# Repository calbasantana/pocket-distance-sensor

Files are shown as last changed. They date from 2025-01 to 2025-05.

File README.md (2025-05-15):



# Introduction
When I had my old car, a 2018 Mazda CX-3, I was always getting frustrated with how hard it was to tell if I was close to another car or not when parking. My car didn't have a built-in proximity sensor, so I decided to take on this project to build one for it.

The idea being that if I had a distance sensor (light-based or sound-based) at the front of the car and hooked up the circuitry inside the car with the small screen, I could make it all work. However, I was in the middle of buying a new car and this project took on a different form, one of being a pocket distance sensor. It certainly isn't perfect, but it is a cool little thing. In the future, I would love to make it more compact.

# Materials
This pocket distance sensor makes use of the following:

- 3D-printed case
- Custom PCB
- Hardware parts

In the following sections, I will get into more details about each.

## 3D-Printed Case

I decided to go with something simple; something that could hold the battery and the screen with everything else in between.



There are a total of 4 files attached here for this case:

- Case Top
- Case Bottom
- Battery Cover
- 4X Magnet Cover

I personally did not end up using the Battery Cover I designed and I found the Magnet Covers to be unnecessary if you're using strong glue to keep the magnets in their place.

### Specifications & Material(s)
Below you can find the printer and material used.
#### 3D Printer
 Original Prusa Mini+
#### Material(s)
* [INLAND True Red PLA ($25.99)](https://www.amazon.com/Inland-PLA-Printer-Filament-1-75mm/dp/B09P22PTGG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
)

#### Software
 PrusaSlicer

##### Settings
  Layer Height: .2mm \
  Infill: 30% \
  Supports: Everywhere \
  Estimated Printing Time: 8 hours and 1 minutes

## Custom PCB

I decided to create a custom PCB for the pico, screen connections, and other hardware pieces to be more compact. I did this using EasyEDA (https://easyeda.com/).

Below you can see the schematics on EasyEDA:



And here you can see the PCB layout:



For convenience, I've attached the Gerber .zip file, which can be uploaded at this website for purchase: https://jlcpcb.com/?href=easyeda-home

Overall, it is very cheap to make a PCB, so I find myself doing large batches - the biggest pain is the shipping.

Once you do have your PCB, make sure to solder it appropriately and attach the active buzzer. See photos below:





## Hardware Parts
The following materials were purchased for this project, but it's cheaper if you already have some available:



* [Pimoroni Pico LiPo ($11)](https://shop.pimoroni.com/products/pimoroni-pico-lipo?variant=39386149093459)

* [3.7V 2500mAh Lipo Rechargeable Battery ($12)](https://www.amazon.com/YDL-2500mAh-battery-Rechargeable-Connector/dp/B07BTY599F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
)

* [Active Buzzer ($7)](https://www.amazon.com/Cylewet-Electronic-Magnetic-Continuous-Arduino/dp/B01N7NHSY6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)

* [HC-SR04 Ultrasonic Sensor ($7)](https://www.amazon.com/DIYables-HC-SR04-Ultrasonic-Arduino-Raspberry/dp/B0BDFLPZ2R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)

* [0.96 inch LCD OLED Display ($13)](https://www.amazon.com/Teyleten-Robot-Display-SSD1306-Raspberry/dp/B0CN373JF4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)

If you don't have any of these materials already available, this project might be expensive at $50 - not including taxes and shipping. If you already have most common items, this might only cost $11 - $24.

# Assembly

This part is pretty straightforward. Put everything where it belongs so it is assembled like in the picture from the top.

# Coding

I've attached the main.py file used for this. Simply download it to your computer and upload it to the Pico. My preferred way of doing this is through Thonny (https://thonny.org/).

The code can also be directly copied from below:

```bash
from machine import Pin, I2C, PWM
from ssd1306 import SSD1306_I2C
from hcsr04 import HCSR04
from time import sleep

# Initialize I2C and SSD1306 display
i2c = I2C(1, scl=Pin(27), sda=Pin(26))
display = SSD1306_I2C(128, 64, i2c)

# Initialize HC-SR04 sensor
sensor = HCSR04(trigger_pin=2, echo_pin=3, echo_timeout_us=1000000)

# Initialize passive buzzer
buzzer = PWM(Pin(22))
buzzer.duty_u16(0)  # Turn off the buzzer initially

prev_distance = 0  # Variable to store the previous distance

while True:
    # Measure distance in centimeters
    distance = sensor.distance_cm()

    # Filter out distances above 400cm
    if distance > 400:
        continue

    print('Distance:', distance, 'cm')

    # Round the distance to two decimal places
    distance_rounded = round(distance, 2)

    # Clear display
    display.fill(0)

    # Show distance on the display
    display.text("Distance:", 0, 0)
    display.text(str(distance_rounded) + " cm", 0, 16)

    # Check distance and display appropriate message
    if distance < 15:
        display.text("Too close!", 32, 32)  # Centered text
        buzzer.freq(1500)  # Set buzzer frequency to 1500Hz
        buzzer.duty_u16(50000)  # Maximum duty cycle for maximum loudness
    elif 15 <= distance < 30:
        display.text("Close enough", 26, 32)  # Centered text
        buzzer.freq(1000)  # Set buzzer frequency to 1500Hz
        buzzer.duty_u16(int((30 - distance) * 8738) + 32767)  # Increase duty cycle as distance decreases
    elif distance >= 30:
        display.text("Keep going", 26, 32)  # Centered text
        buzzer.duty_u16(0)  # Turn off the buzzer

    display.show()

    # Stop the beep if the distance changes
    if distance != prev_distance:
        buzzer.duty_u16(0)  # Turn off the buzzer
        prev_distance = distance

    # Delay for a short period
    sleep(.5)
```

Of course, you can edit this code however you like. I have it set to beep at those different distance because, as I mentioned before, when I was originally designing this, it was with the intention for it to be used with my older car.

## Running the Code

I wanted to provide a quick video of this pocket distance sensor in use:

https://github.com/user-attachments/assets/67f8aee9-af19-4441-ae75-e8cb7f0fee7f

# Tips

The sensor may sometimes give readings that are way off. This is because of how sound-based sensors work. Essentially, one part of the sensor sends out a sound wave, which bounces back and is then incident on the other part of the sensor. Since the speed of sound in air is well-known, this value, alongside the time in between sending the sound wave and receiving it, is used to determine distance between sensor and source. This does pose issues if the source of the sound moves (so if you move your hand too much while holding the sensor) or if the angle is tilted from the survey or if the target surface has grooves that diffuse sound waves in an odd pattern. These are all things to keep in mind and a good reason for why people often opt for light-based distance sensors instead.

I believe the sensor I used here is rated for about 2 meters of accuracy, but realistically, I wouldn't put it past 1 meter here.

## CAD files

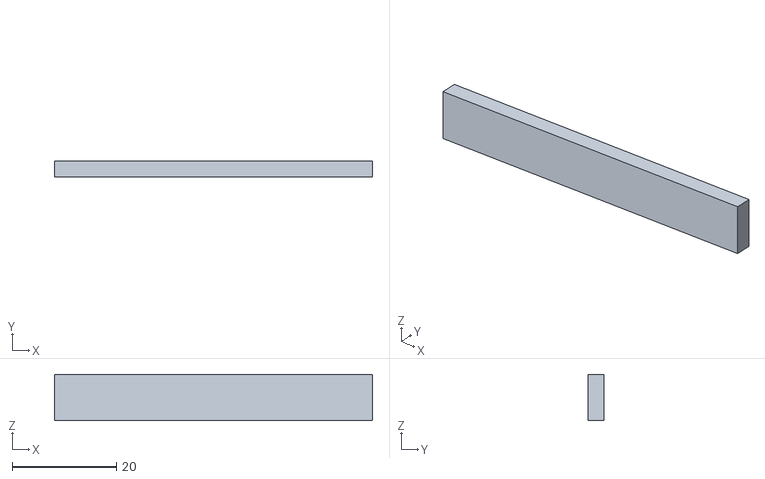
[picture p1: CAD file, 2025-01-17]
Battery Cover.stl
60.9 x 3.00 x 8.81

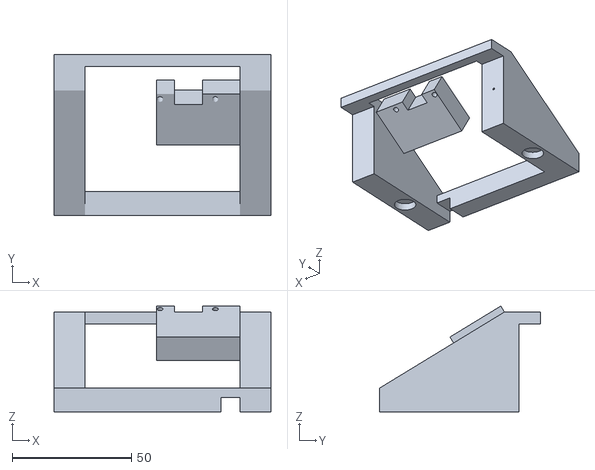
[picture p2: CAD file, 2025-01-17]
Case Top.stl
91.0 x 67.5 x 44.4

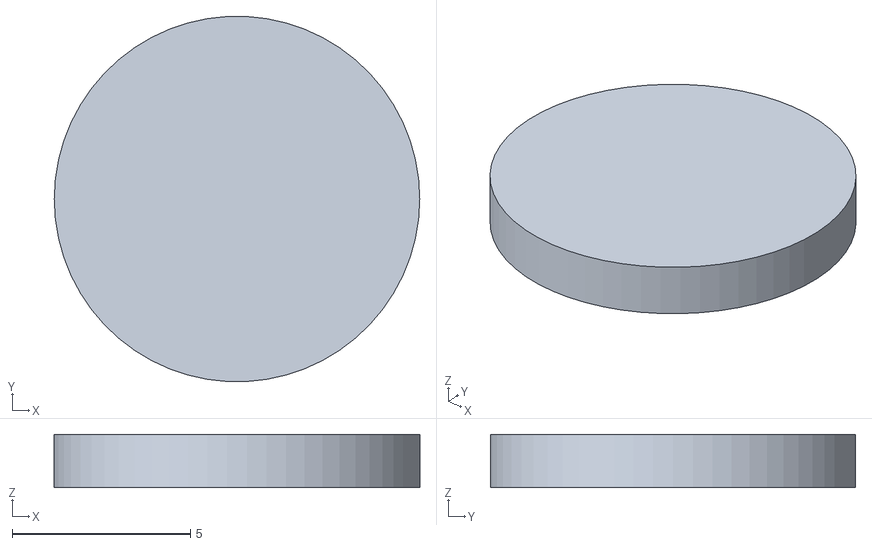
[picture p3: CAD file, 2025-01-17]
Magnet Cover.stl
10.2 x 10.2 x 1.50

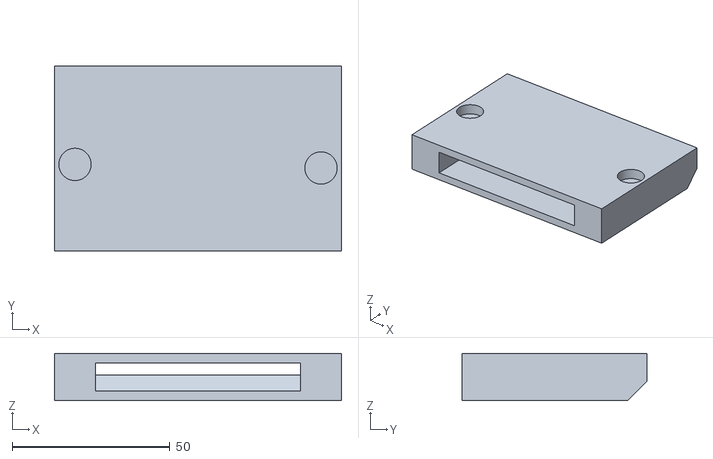
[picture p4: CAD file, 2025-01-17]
Case Bottom.stl
91.0 x 58.5 x 15.0
